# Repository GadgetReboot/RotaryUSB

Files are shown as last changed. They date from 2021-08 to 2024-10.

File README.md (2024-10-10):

# RotaryUSB
LS30 Rotary Joystick to USB Interface

  Required Arduino libraries, board files, and utilities:<br>
 <br>
  Before the ATTiny85 can be programmed with the sketch from the IDE, the Micronucleus bootloader must be flashed <br>
  with the ATTiny85 on a breadboard and using an Uno as a programmer (or some other method).<br>
  Once that is done and the ATTiny85 is installed on the USB PCB, it will appear as a USB device when plugged in and <br>
  the IDE can program it over USB.<br>
 <br>
  Download Micronucleus bootloader v2.4 file t85_default.hex from<br>
  https://github.com/ArminJo/micronucleus-firmware/tree/ca7216847e6bbf695067076b6c07703ca2d96761/firmware/releases<br>
 <br>
  To upload t85_default.hex bootloader, an Arduino Uno can be used as an ISP programmer to program an ATTiny85<br>
  on a breadboard. A wiring diagram can be found here as a reference<br>
  https://homemadehardware.com/guides/programming-an-attiny85/<br>
  but just use that site as a wiring example between the Uno programmer and the ATTiny85 on a breadboard.<br>
  Setup the Uno as a programmer by loading the IDE example sketch &quot;ArduinoISP&quot; (which comes with the IDE) <br>
  and program the Uno. Now the Uno can act as a programmer between the computer and the ATTiny chip.<br>
  Add a capacitor (around 1 to 10 uF) between the Uno Reset and Ground pins (capacitor + to Reset and - to Gnd)<br>
  This prevents the Uno from getting reset by the computer when attempting to program the ATTiny.<br>
  Then wire up the connections between Uno and ATTiny85 to flash the bootloader with the following instructions.<br>
 <br>
  This example procedure was done on Windows 10. Similar instructions can be found for Linux/Mac by following the<br>
  general process and using the equivalent versions of tools available on the other OS. <br>
 <br>
  Download avrdude.conf and avrdude.exe from<br>
  https://github.com/ArminJo/micronucleus-firmware/tree/ca7216847e6bbf695067076b6c07703ca2d96761/windows_exe<br>
  Place the avrdude files in the same folder as the previously downloaded micronucleus bootloader file t85_default.hex<br>
  Also place the flash_bootloader.bat file from the github project https: github.com/GadgetReboot/RotaryUSB in the same folder.<br>
  Run flash_bootloder.bat and it will launch avrdude with the settings needed to flash t85_default.hex into the ATTiny85<br>
  A commandline parameter is needed to specify the com port of the Uno being used as a programmer.<br>
  That will be the same COM port that was used in the IDE to set the Uno as a programmer.<br>
  example of a valid command line: flash_bootloader.bat COM1<br>
  If the programming fails but the wiring seems good, it's possible the fuses in the ATTiny need to be reset if the<br>
  chip was previously configured to disable the reset pin and use it as a GPIO. Reset is needed for programming<br>
  so either a different chip should be used, or a high voltage programmer must be used to reset the fuses and <br>
  allow programming again. <br>
  Example fuse reset procedure: https: www.youtube.com/watch?v=JskwC4bhgx4<br>
 <br>
  With the ATTiny85 programmed with a bootloader, the Uno programmer is no longer needed.<br>
  Plug the ATTiny85 into the USB board and plug it into a USB port on a computer.<br>
  If the device doesn't show up, <br>
  Windows drivers may need to be installed to recognize the board as a USB device.<br>
  The ones that worked in this Windows 10 example were<br>
  https://github.com/digistump/DigistumpArduino/releases/download/1.6.7/Digistump.Drivers.zip<br>
  DPinst64.exe was run, which installed drivers and allowed the ATTiny85 board to appear as a USB Keyboard<br>
  when the sketch was flashed.<br>
 <br>
  When the USB board is ready to be programmed with the sketch over USB with the Arduino IDE,<br>
  Tested with Arduino IDE 2.3.3 on Windows 10 using:<br>
  Micronucleus bootloader 2.4 t85_default.hex flashed to ATTiny85 using avrdude tool, run with flash_bootloader.bat<br>
  Install Arduino IDE Bounce2 library 2.1 (some newer versions may not compile for some reason)<br>
  Install Arduino IDE Board Manager: Digistump AVR Boards 1.6.7 to add Digispark board support:<br>
  Add url to Arduino preferences/additional board URLs <br>
  https://raw.githubusercontent.com/digistump/arduino-boards-index/master/package_digistump_index.json<br>
  Then in the Tools menu to add board support, search for the Digistump AVR 1.6.7 board file and install it<br>
  With this sketch open, choose the target board Digispark Default 16.5 MHz from the Tools menu.<br>
  no other options should be needed from the Tools menu to configure the project for uploading<br>
 <br>
  Now the sketch should compile and upload.<br>
  Note that the board should be unplugged prior to starting a sketch upload from the IDE. <br>
  The IDE will say when it is time to plug in the USB board (with a 60 second timeout) and it will program it.<br>
  It may take a few seconds for the OS to detect the USB device before the IDE can program it.<br>
 <br>
  After programming, if the board is power cycled, it should appear as a USB keyboard and the rotating<br>
  joystick should produce keystrokes when moved. The keystrokes can be changed within the sketch, especially<br>
  if two boards are used on the same computer for 2 player games.<br>
  Each board should have unique keystrokes assigned and when both are plugged into the same computer, <br>
  they should behave like the same keyboard, just sending different keys.

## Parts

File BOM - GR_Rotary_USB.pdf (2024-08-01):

Rotary USB BOM

Item # | Reference Designator | Qty | Manufacturer | Mfg Part # | Description / Value | Package/Footprint | Type | Instructions / Notes
1 | C2 | 1 | Samsung | CL21B104KBCNNWC | CAP CER 0.1UF 50V X7R 0805 | 0805 | SMD
2 | C1 | 1 | Samsung | CL21A475KAQNNNE | CAP CER 4.7UF 25V X5R 0805 | 0805 | SMD
3 | D1 D2 | 2 | Vishay | BZD27C3V6P-E3-08 | DIODE ZENER 3.6V 800MW DO219AB | DO-219AB (SMF) | SMD
4 | F1 | 1 | Bourns | MF-FSMF050X-2 | PTC RESET FUSE 6V 500MA 0603 | 0603 | SMD
5 | J3 | 0 | | | | | | Do Not Install
6 | J2 | 1 | Adam Tech | PH1RA-13-UA | CONN HEADER R/A 13POS 2.54MM | 13POS | THRU-HOLE
7 | J1 | 1 | Amphenol | 10103594-0001LF | CONN RCPT USB2.0 MICRO B SMD R/A | USB Micro SMD | SMD
8 | R2 R3 | 2 | Panasonic | ERJ-3EKF66R5V | RES SMD 66.5 OHM 1% 1/10W 0603 | 0603 | SMD
9 | R1 | 1 | Panasonic | ERJ-3GEYJ152V | RES SMD 1.5K OHM 5% 1/10W 0603 | 0603 | SMD
10 | U1 | 1 | TE Connectivity | 1-2199298-2 | CONN IC DIP SOCKET 8POS TIN | DIP8 | THRU-HOLE
11 | U1 | 1 | Microchip | ATTINY85-20PU | IC MCU 8BIT 8KB FLASH 8DIP | DIP8 | THRU-HOLE | Install in U1 socket

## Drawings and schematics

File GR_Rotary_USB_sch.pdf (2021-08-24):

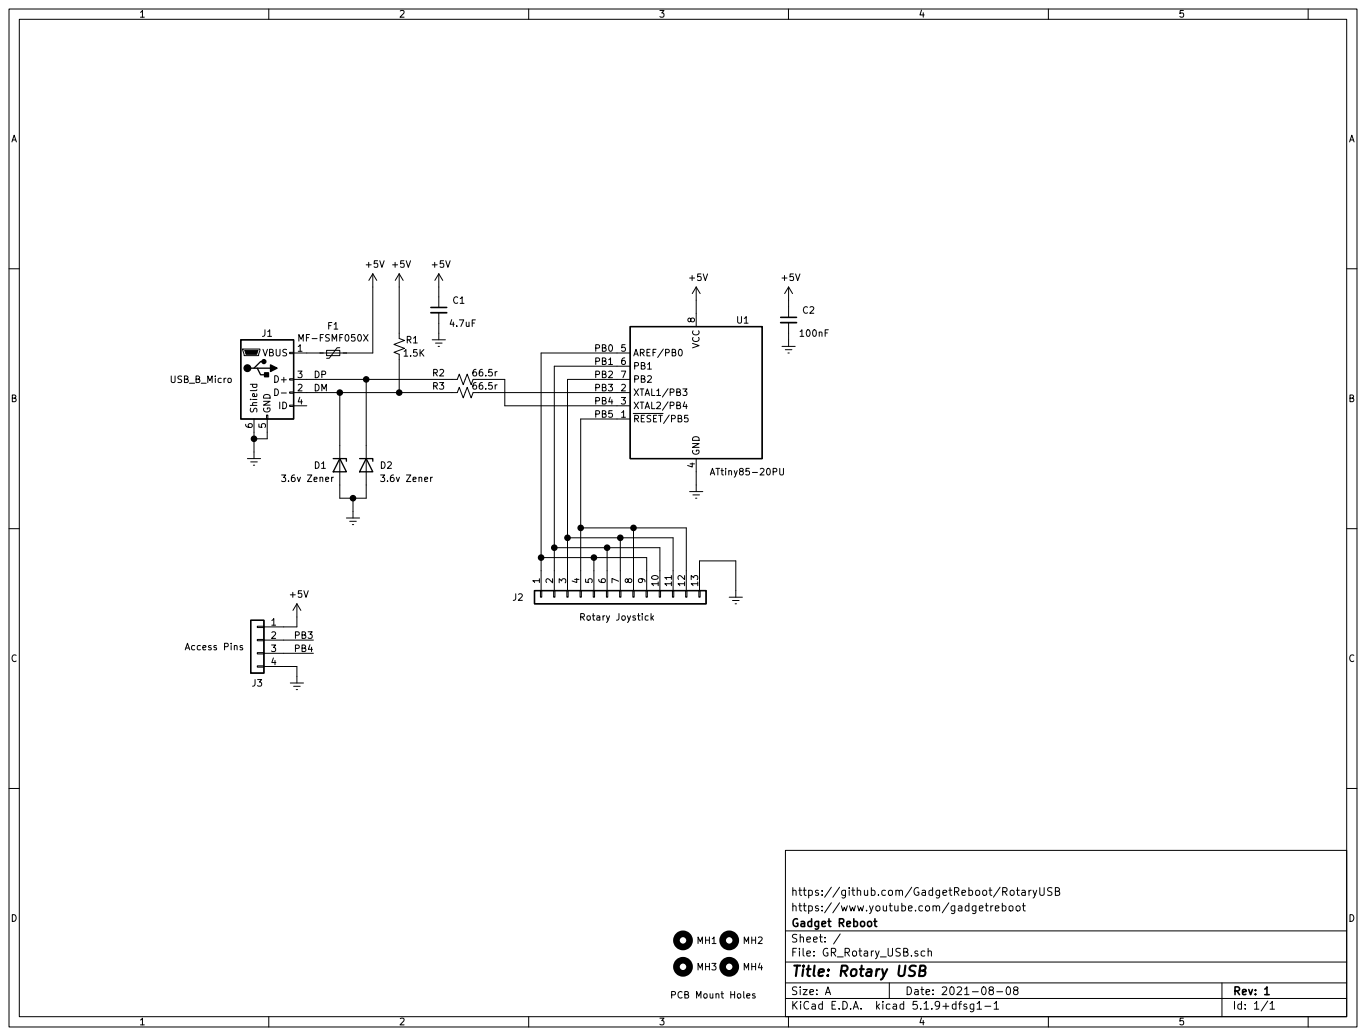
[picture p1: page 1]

https://github.com/GadgetReboot/RotaryUSB
https://www.youtube.com/gadgetreboot
File: GR_Rotary_USB.sch Sheet: / Gadget Reboot

Id: 1/1 Title: Rotary USB

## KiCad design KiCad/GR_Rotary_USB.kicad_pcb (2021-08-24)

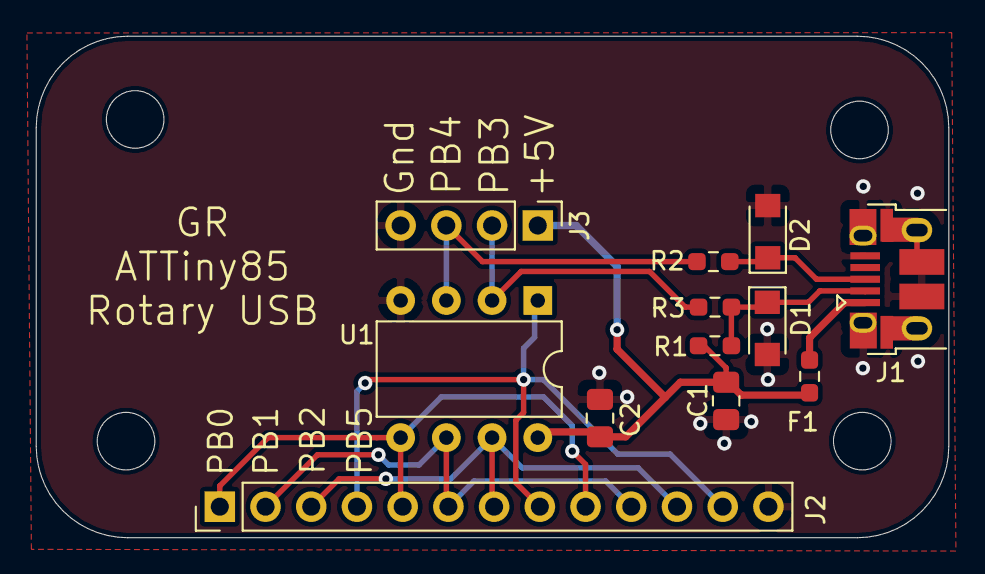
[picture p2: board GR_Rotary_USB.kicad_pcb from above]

Board: 2 copper layers, 50.7 x 27.9 mm, 16 parts (0 on the bottom side), 11 nets.

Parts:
C1: 4.7uF; C_0805_2012Metric_Pad1.18x1.45mm_HandSolder
C2: 100nF; C_0805_2012Metric_Pad1.18x1.45mm_HandSolder
D1, D2: 3.6v Zener; D_SMF
F1: MF-FSMF050X; R_0603_1608Metric_Pad0.98x0.95mm_HandSolder
J1: USB_B_Micro; USB_Micro-B_Amphenol_10103594-0001LF_Horizontal
J2: Rotary Joystick; PinHeader_1x13_P2.54mm_Vertical
J3: Access Pins; PinHeader_1x04_P2.54mm_Vertical
MH1, MH2, MH3, MH4: MountingHole; MountingHole_3.2mm_M3
R1: 1.5K; R_0603_1608Metric_Pad0.98x0.95mm_HandSolder
R2, R3: 66.5r; R_0603_1608Metric_Pad0.98x0.95mm_HandSolder
U1: ATtiny85-20PU; DIP-8_W7.62mm

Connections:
+5V: C1.1, C2.1, F1.1, J3.1, R1.1, U1.8
/DM: D1.1, J1.2, R1.2, R3.2
/DP: D2.1, J1.3, R2.2
/PB0: J2.1, J2.5, J2.9, U1.5
/PB1: J2.2, J2.6, J2.10, U1.6
/PB2: J2.3, J2.7, J2.11, U1.7
/PB3: J3.2, R3.1, U1.2
/PB4: J3.3, R2.1, U1.3
/PB5: J2.4, J2.8, J2.12, U1.1
GNDREF: C1.2, C2.2, D1.2, D2.2, J1.5, J1.6, J2.13, J3.4, U1.4
unnamed: F1.2, J1.1

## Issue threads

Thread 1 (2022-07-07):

Nowhere to buy?

spotUP, 2022-07-07:
Hello! I have an ”issue” :)
I can’t find anywhere to buy assembled boards?
Could i buy two from you?

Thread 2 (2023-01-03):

pins wrong

taneofpain, 2023-01-03:
hi i built this but it doesn't work for me.  i think the problem might be the pin-out? The LS-30 GND pin is at 7 and if i understand this project correctly it expects the GND pin to be at 13?

GadgetReboot, 2023-01-04:
I don't know if there's different versions with different pinouts (I know there's a Data East version of the joystick) but one thing I believe is the cable is not 1 to 1 pinout.   I think the original cable has an "R" marking and that's the one that plugs into  the joystick (maybe that's where ground is at pin 7), and the other end should map ground over to the end, which is what the circuit expects.

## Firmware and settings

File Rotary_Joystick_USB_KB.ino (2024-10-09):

// LS-30 Rotary Joystick to MAME Interface
// using ATTiny85 with vUSB micronucleus bootloader
//
// Reads the 12 rotary switches and detects when the position has changed.
// Generates a usb keyboard key press to indicate a clockwise or
// counter-clockwise movement has occurred.
//
// Target Hardware:  ATTiny85 running Micronucleus bootloader 
//                   Rotary Joystick with 12 position switch
//
// Connections:
// Joystick Harness Pin     ATTiny85 Port B Pin
// 1, 5, 9                         0
// 2, 6, 10                        1
// 3, 7, 11                        2
// 4, 8, 12                        5
// 13                             GND
//
//
// Required Arduino libraries, board files, and utilities:
//
// Before the ATTiny85 can be programmed with the sketch from the IDE, the Micronucleus bootloader must be flashed 
// with the ATTiny85 on a breadboard and using an Uno as a programmer (or some other method).
// Once that is done and the ATTiny85 is installed on the USB PCB, it will appear as a USB device when plugged in and 
// the IDE can program it over USB.
//
// Download Micronucleus bootloader v2.4 file t85_default.hex from
//    https://github.com/ArminJo/micronucleus-firmware/tree/ca7216847e6bbf695067076b6c07703ca2d96761/firmware/releases
//
// To upload t85_default.hex bootloader, an Arduino Uno can be used as an ISP programmer to program an ATTiny85
// on a breadboard.  A wiring diagram can be found here as a reference
// https://homemadehardware.com/guides/programming-an-attiny85/
// but just use that site as a wiring example between the Uno programmer and the ATTiny85 on a breadboard.
// Setup the Uno as a programmer by loading the IDE example sketch "ArduinoISP" (which comes with the IDE) 
// and program the Uno.  Now the Uno can act as a programmer between the computer and the ATTiny chip.
// Add a capacitor (around 1 to 10 uF) between the Uno Reset and Ground pins (capacitor + to Reset and - to Gnd)
// This prevents the Uno from getting reset by the computer when attempting to program the ATTiny.
// Then wire up the connections between Uno and ATTiny85 to flash the bootloader with the following instructions.
//
// This example procedure was done on Windows 10.  Similar instructions can be found for Linux/Mac by following the
// general process and using the equivalent versions of tools available on the other OS. 
//
// Download avrdude.conf and avrdude.exe from
//    https://github.com/ArminJo/micronucleus-firmware/tree/ca7216847e6bbf695067076b6c07703ca2d96761/windows_exe
// Place the avrdude files in the same folder as the previously downloaded micronucleus bootloader file t85_default.hex
// Also place the flash_bootloader.bat file from the github project https://github.com/GadgetReboot/RotaryUSB in the same folder.
// Run flash_bootloder.bat and it will launch avrdude with the settings needed to flash t85_default.hex into the ATTiny85
// A commandline parameter is needed to specify the com port of the Uno being used as a programmer.
// That will be the same COM port that was used in the IDE to set the Uno as a programmer.
// example of a valid command line:   flash_bootloader.bat COM1
// If the programming fails but the wiring seems good, it's possible the fuses in the ATTiny need to be reset if the
// chip was previously configured to disable the reset pin and use it as a GPIO.  Reset is needed for programming
// so either a different chip should be used, or a high voltage programmer must be used to reset the fuses and 
// allow programming again.  
// Example fuse reset procedure: https://www.youtube.com/watch?v=JskwC4bhgx4
//
// With the ATTiny85 programmed with a bootloader, the Uno programmer is no longer needed.
// Plug the ATTiny85 into the USB board and plug it into a USB port on a computer.
// If the device doesn't show up, 
// Windows drivers may need to be installed to recognize the board as a USB device.
// The ones that worked in this Windows 10 example were
// https://github.com/digistump/DigistumpArduino/releases/download/1.6.7/Digistump.Drivers.zip
// DPinst64.exe was run, which installed drivers and allowed the ATTiny85 board to appear as a USB Keyboard
// when the sketch was flashed.
//
// When the USB board is ready to be programmed with the sketch over USB with the Arduino IDE,
// Tested with Arduino IDE 2.3.3 on Windows 10 using:
//             Micronucleus bootloader 2.4  t85_default.hex flashed to ATTiny85 using avrdude tool, run with flash_bootloader.bat
//             Install Arduino IDE Bounce2 library 2.1 (some newer versions may not compile for some reason)
//             Install Arduino IDE Board Manager: Digistump AVR Boards 1.6.7 to add Digispark board support:
//     Add url to Arduino preferences/additional board URLs 
//     https://raw.githubusercontent.com/digistump/arduino-boards-index/master/package_digistump_index.json
//     Then in the Tools menu to add board support, search for the Digistump AVR 1.6.7 board file and install it
//     With this sketch open, choose the target board Digispark Default 16.5 MHz   from the Tools menu.
//     no other options should be needed from the Tools menu to configure the project for uploading
//
// Now the sketch should compile and upload.
// Note that the board should be unplugged prior to starting a sketch upload from the IDE. 
// The IDE will say when it is time to plug in the USB board (with a 60 second timeout) and it will program it.
// It may take a few seconds for the OS to detect the USB device before the IDE can program it.
//
// After programming, if the board is power cycled, it should appear as a USB keyboard and the rotating
// joystick should produce keystrokes when moved.  The keystrokes can be changed within the sketch, especially
// if two boards are used on the same computer for 2 player games.
// Each board should have unique keystrokes assigned and when both are plugged into the same computer, 
// they should behave like the same keyboard, just sending different keys.
//
// Gadget Reboot
// https://www.youtube.com/@gadgetreboot


#include "DigiKeyboard.h"
#include <Bounce2.h>

#define debounceTime 30  // switch debounce in ms
#define switchOne 0      // rotary switch input pins on DigiSpark
#define switchTwo 1
#define switchThree 2
#define switchFour 5

byte lastState = 0;  // previous stored joystick reading
byte curState = 0;   // current joystick reading to evaluate against last reading

// create debouncer objects for inputs
Bounce debouncedOne = Bounce();
Bounce debouncedTwo = Bounce();
Bounce debouncedThree = Bounce();
Bounce debouncedFour = Bounce();

void setup() {

  DigiKeyboard.sendKeyStroke(0);

  pinMode(switchOne, INPUT_PULLUP);
  debouncedOne.attach(switchOne);       // setup the bounce instance
  debouncedOne.interval(debounceTime);  // debounce interval in ms

  pinMode(switchTwo, INPUT_PULLUP);
  debouncedTwo.attach(switchTwo);       // setup the bounce instance
  debouncedTwo.interval(debounceTime);  // debounce interval in ms

  pinMode(switchThree, INPUT_PULLUP);
  debouncedThree.attach(switchThree);     // setup the bounce instance
  debouncedThree.interval(debounceTime);  // debounce interval in ms

  pinMode(switchFour, INPUT_PULLUP);
  debouncedFour.attach(switchFour);      // setup the bounce instance
  debouncedFour.interval(debounceTime);  // debounce interval in ms

  // take an initial reading of the rotary switches

  debouncedOne.update();           // update the switch status
  if (debouncedOne.read() == LOW)  // if a switch was grounded, update the status register
    bitSet(curState, 0);

  debouncedTwo.update();           // update the switch status
  if (debouncedTwo.read() == LOW)  // if a switch was grounded, update the status register
    bitSet(curState, 1);

  debouncedThree.update();           // update the switch status
  if (debouncedThree.read() == LOW)  // if a switch was grounded, update the status register
    bitSet(curState, 2);

  debouncedFour.update();           // update the switch status
  if (debouncedFour.read() == LOW)  // if a switch was grounded, update the status register
    bitSet(curState, 3);

  lastState = curState;  // make last and current readings identical to avoid a false output trigger on power up

}  // end setup()


void loop() {

  DigiKeyboard.update();
  readJoystick();     // read the current rotary switch states into curState register
  processJoystick();  // determine if a rotation has occurred and set a flag if so

}  // end loop()


// read the joystick rotary switches into the curState register
void readJoystick() {

  debouncedOne.update();      // update the debouncer status
  if (debouncedOne.fell()) {  // if a switch was grounded, update the status register
    curState = 0;             // clear the register and re-build it from current switch reading
    bitSet(curState, 0);
  }

  debouncedTwo.update();      // update the debouncer status
  if (debouncedTwo.fell()) {  // if a switch was grounded, update the status register
    curState = 0;             // clear the register and re-build it from current switch reading
    bitSet(curState, 1);
  }

  debouncedThree.update();      // update the debouncer status
  if (debouncedThree.fell()) {  // if a switch was grounded, update the status register
    curState = 0;               // clear the register and re-build it from current switch reading
    bitSet(curState, 2);
  }

  debouncedFour.update();      // update the debouncer status
  if (debouncedFour.fell()) {  // if a switch was grounded, update the status register
    curState = 0;              // clear the register and re-build it from current switch reading
    bitSet(curState, 3);
  }

}  // end readJoystick()


// check if rotary switches are different from last saved reading
// and set the appropriate flag for the detected rotation
void processJoystick() {

  int diff = (lastState - curState);  // check for a difference in joystick readings

  // clockwise rotation has occurred
  if (((diff < 0) && !((lastState == B0001) && (curState == B1000))) | ((diff > 0) && (lastState == B1000) && (curState == B0001))) {

    DigiKeyboard.sendKeyStroke(KEY_R, MOD_SHIFT_LEFT);

    // debugLastCur();  // show debug last and current info on usb keyboard out

  }

  // counter-clockwise rotation has occurred
  else if (((diff > 0) && !((lastState == B1000) && (curState == B0001))) | ((diff < 0) && (lastState == B0001) && (curState == B1000))) {

    DigiKeyboard.sendKeyStroke(KEY_L, MOD_SHIFT_LEFT);

    // debugLastCur();  // show debug last and current info on usb keyboard out
  }
  lastState = curState;

}  // end processJoystick()


void debugLastCur() {

  DigiKeyboard.println();
  DigiKeyboard.print("Last:");
  switch (lastState) {
    case 1:
      DigiKeyboard.println("0001");
      break;
    case 2:
      DigiKeyboard.println("0010");
      break;
    case 4:
      DigiKeyboard.println("0100");
      break;
    case 8:
      DigiKeyboard.println("1000");
      break;
    default:
      DigiKeyboard.println("nul");
      break;
  }


  DigiKeyboard.print("Curr:");
  switch (curState) {
    case 1:
      DigiKeyboard.println("0001");
      break;
    case 2:
      DigiKeyboard.println("0010");
      break;
    case 4:
      DigiKeyboard.println("0100");
      break;
    case 8:
      DigiKeyboard.println("1000");
      break;
    default:
      DigiKeyboard.println("nul");
      break;
  }
}
